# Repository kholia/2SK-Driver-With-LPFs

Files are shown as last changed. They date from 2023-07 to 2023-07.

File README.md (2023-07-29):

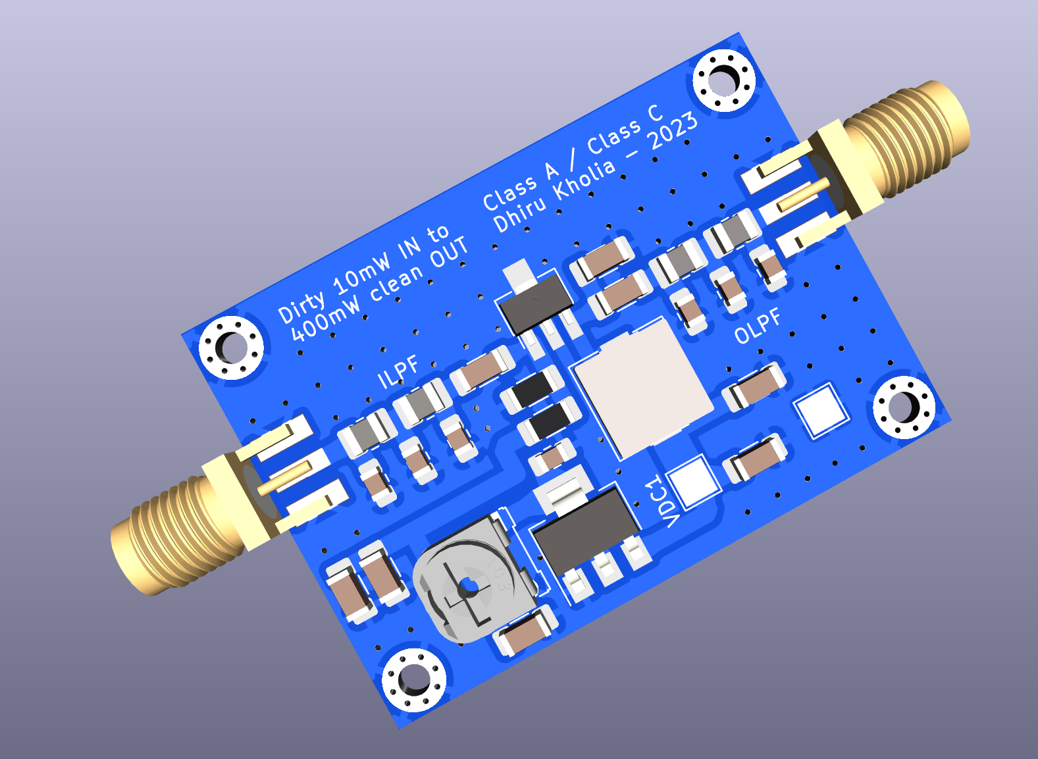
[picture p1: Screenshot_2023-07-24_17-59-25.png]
PCB render


This PCB was validated in July, 2023.

It outputs around 210mW into a dummy load @ 28 MHz even without any matching at
the output side. This is more than enough to drive RD16HHF1-501 easily.

Input is ~10mW straight from a Si5351 clone module.

We should probably add some simple LC matching at the output side one day.

Measurements on tinySA after 50 dB attentuation:

```
-24.4 dBm - Fc

-71.9 dBm -> second harmonic

dBc = ~47
```

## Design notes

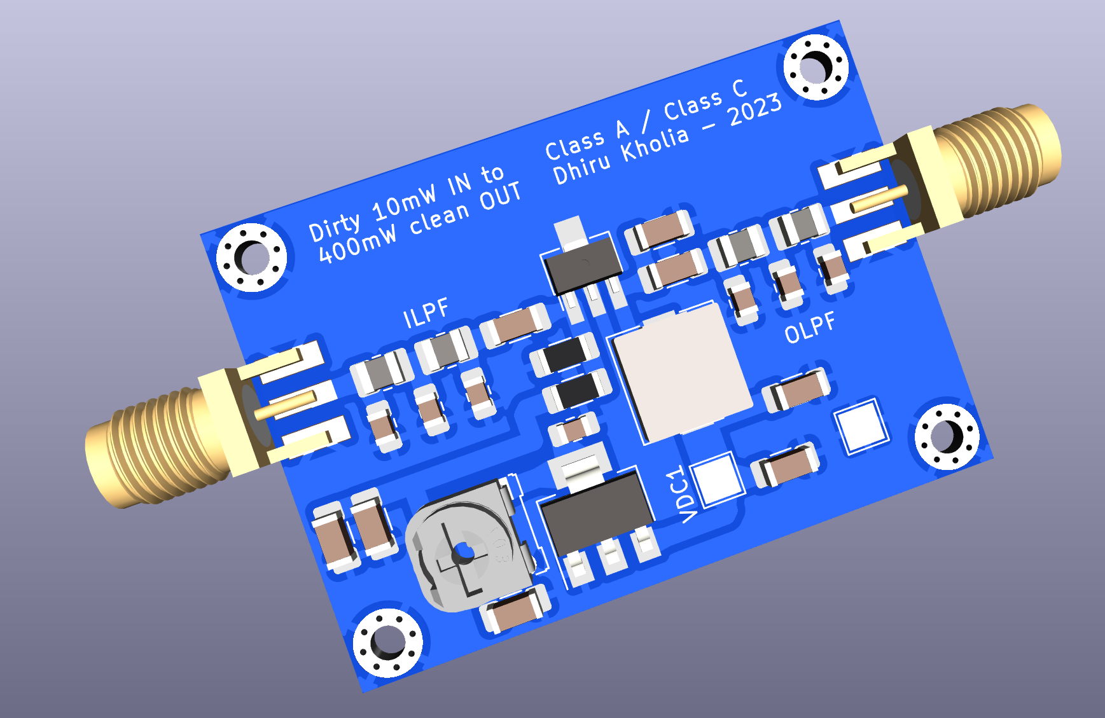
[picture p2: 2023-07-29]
Screenshot_2023-07-24_17-48-51.png

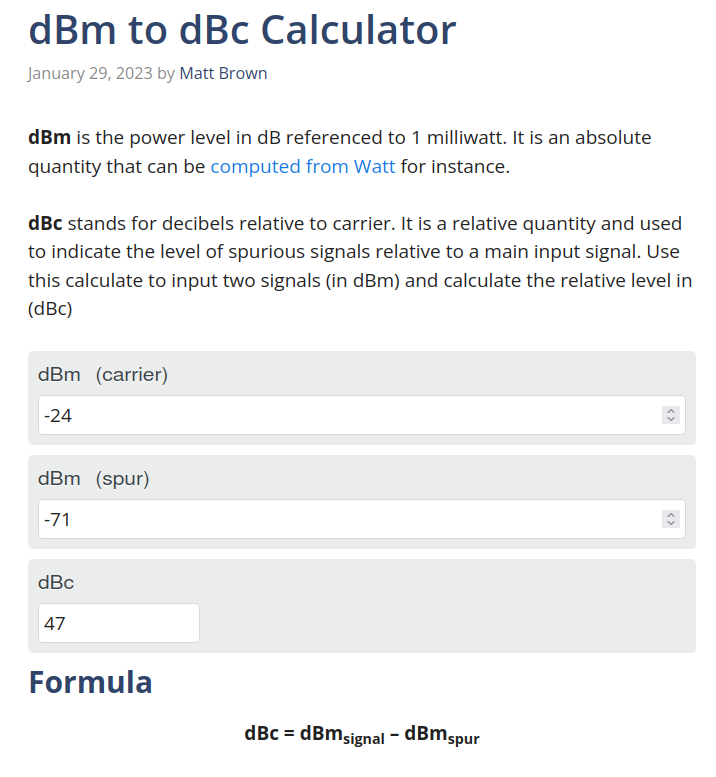
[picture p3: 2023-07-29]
Screenshot_2023-07-20_23-33-54.png

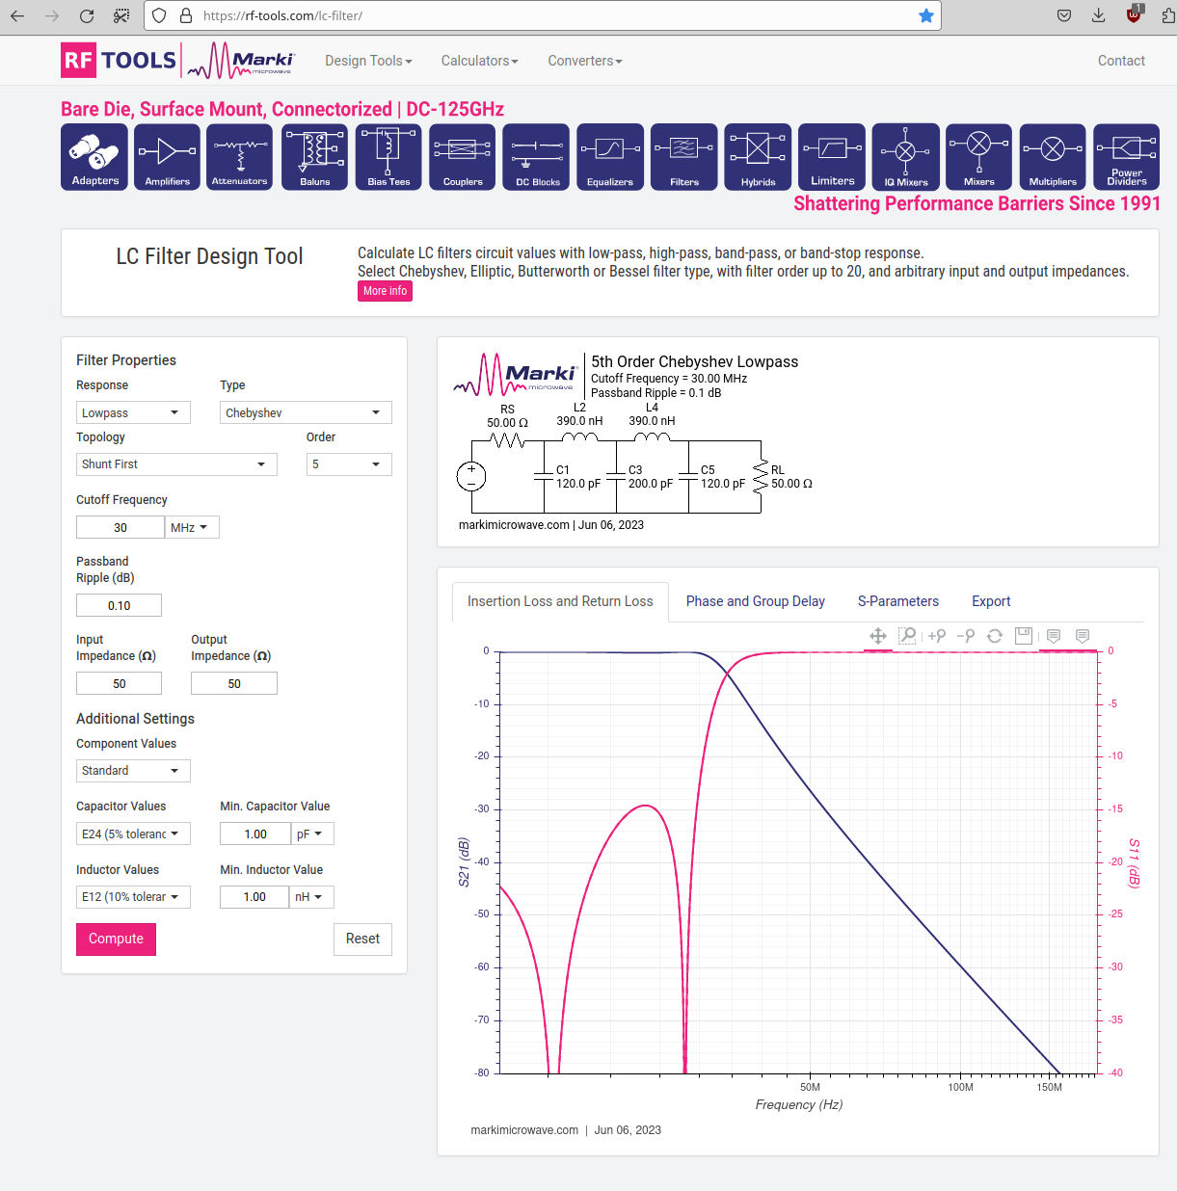
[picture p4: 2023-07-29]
simulations/Screenshot_2023-06-06_22-12-02.png

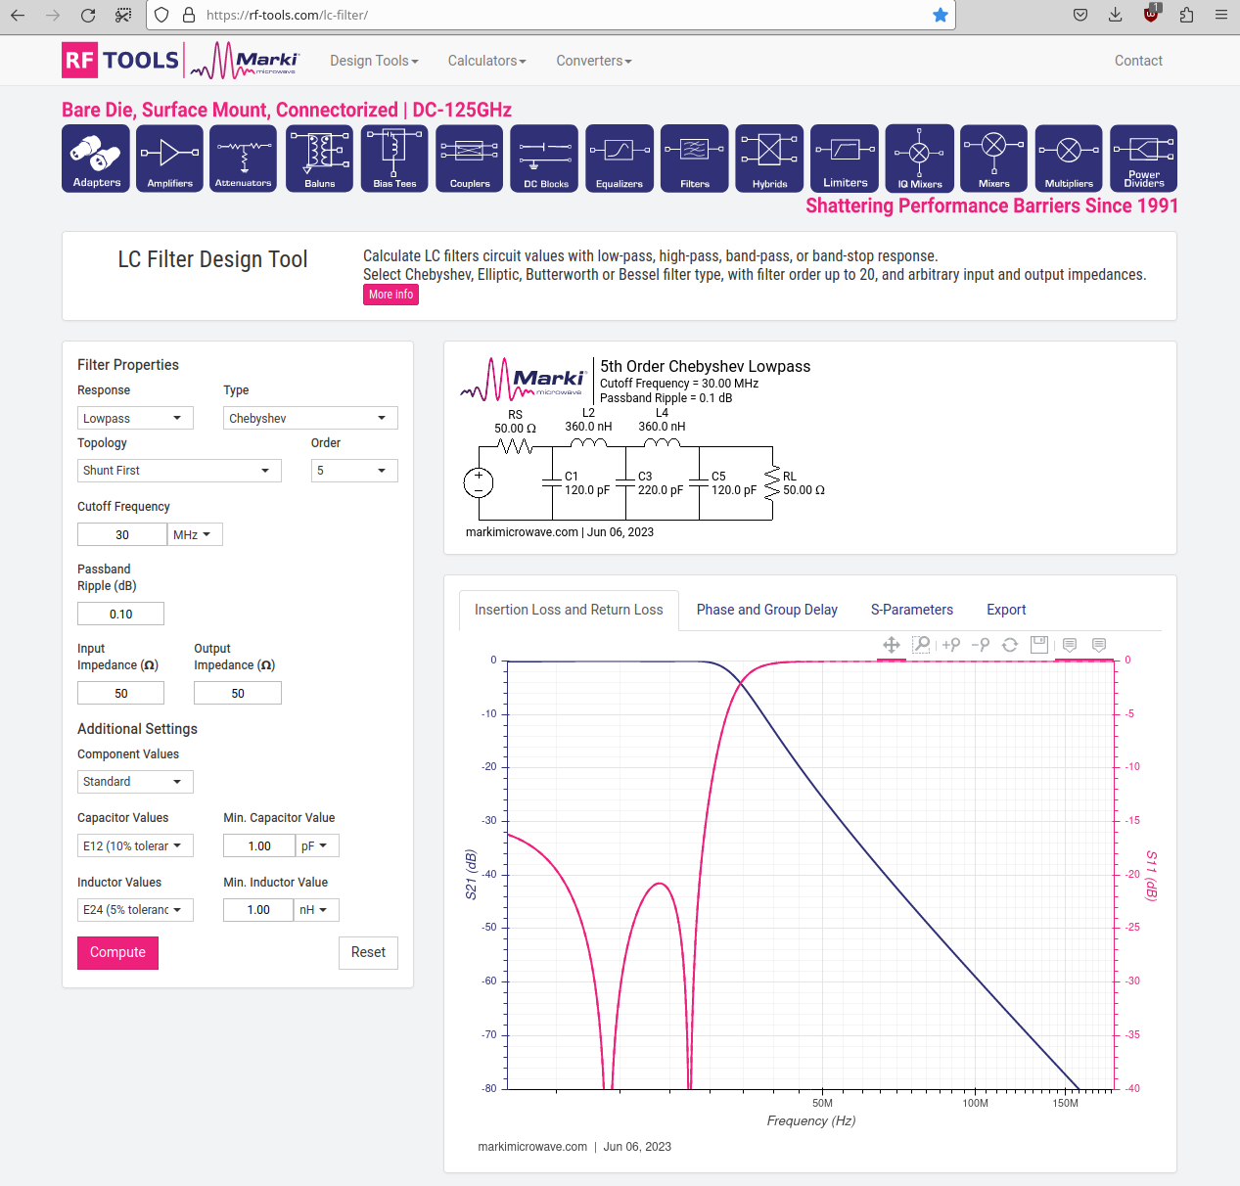
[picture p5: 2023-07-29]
simulations/Screenshot_2023-06-06_21-58-15.png

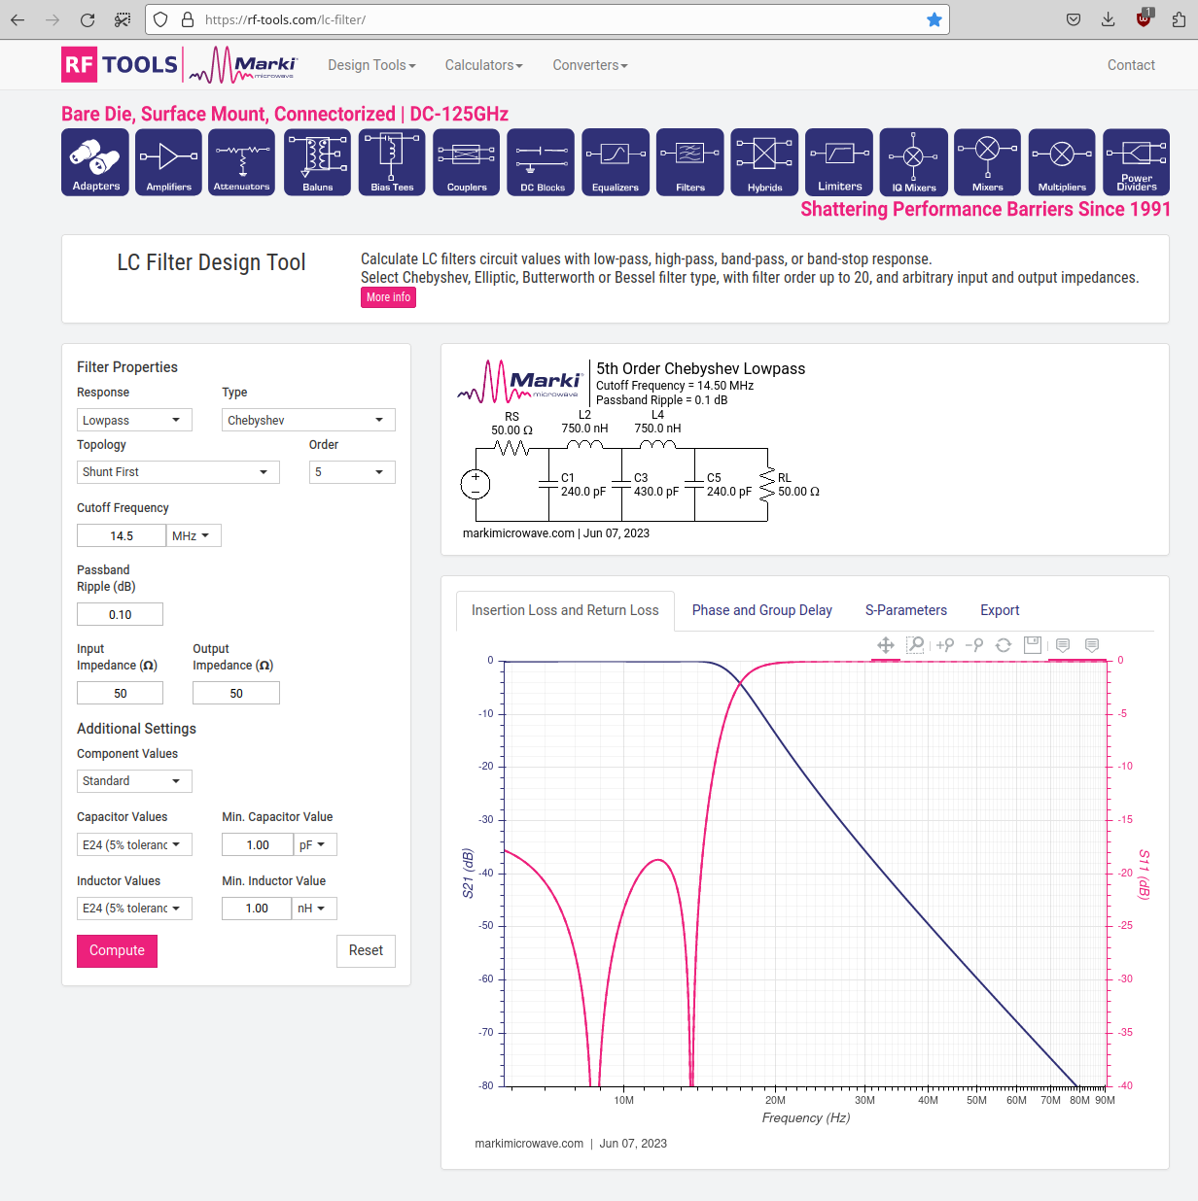
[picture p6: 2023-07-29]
simulations/Screenshot_2023-06-07_12-02-53.png

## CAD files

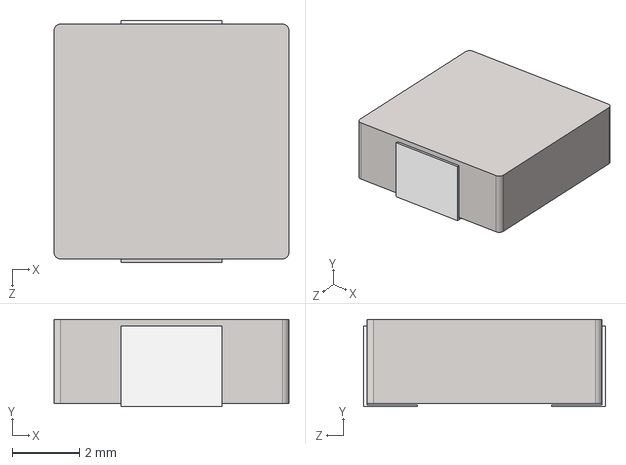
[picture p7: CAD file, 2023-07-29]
models/Inductor_7x7x2.5.STEP
7.00 x 2.60 x 7.20 mm

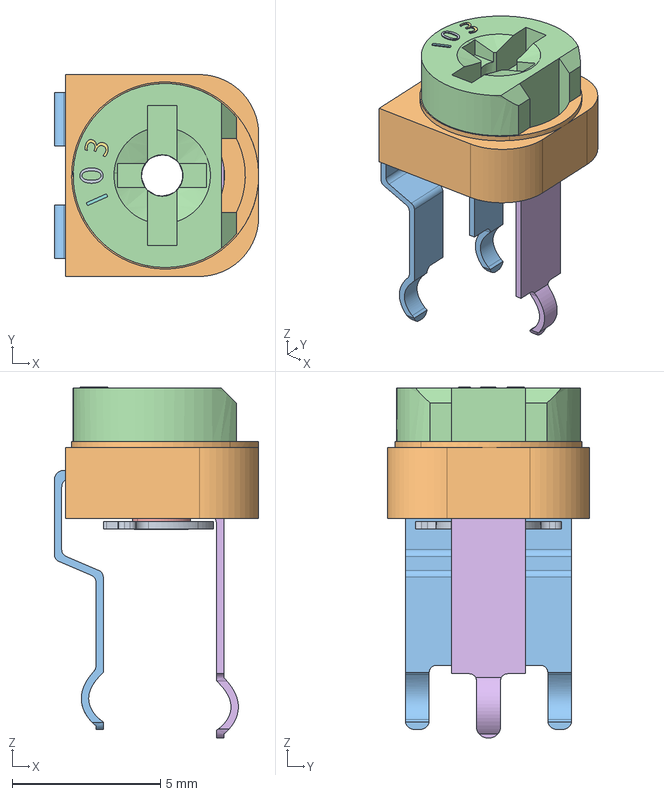
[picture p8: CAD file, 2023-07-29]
models/Poti_10kohm.stp
6.88 x 6.80 x 11.8 mm

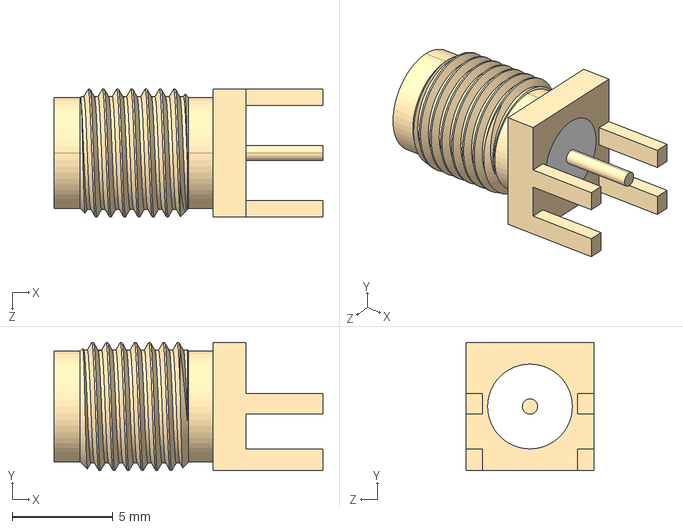
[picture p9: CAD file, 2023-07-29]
models/CON-SMA-EDGE-S--3DModel-STEP-56544.STEP
13.3 x 6.35 x 6.35 mm

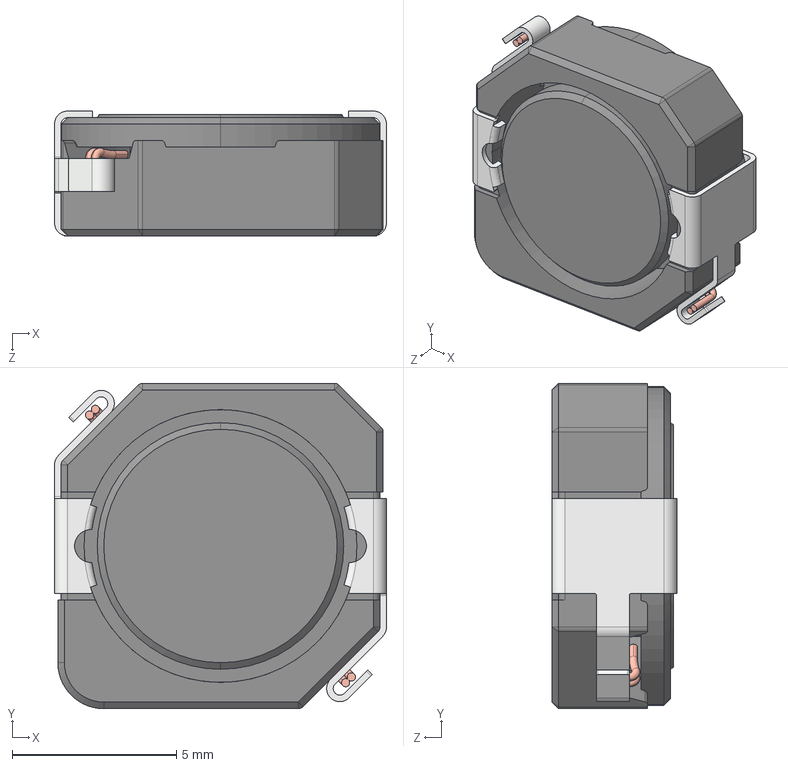
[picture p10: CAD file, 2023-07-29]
models/CDRH104R.STEP
10.1 x 9.90 x 3.80 mm

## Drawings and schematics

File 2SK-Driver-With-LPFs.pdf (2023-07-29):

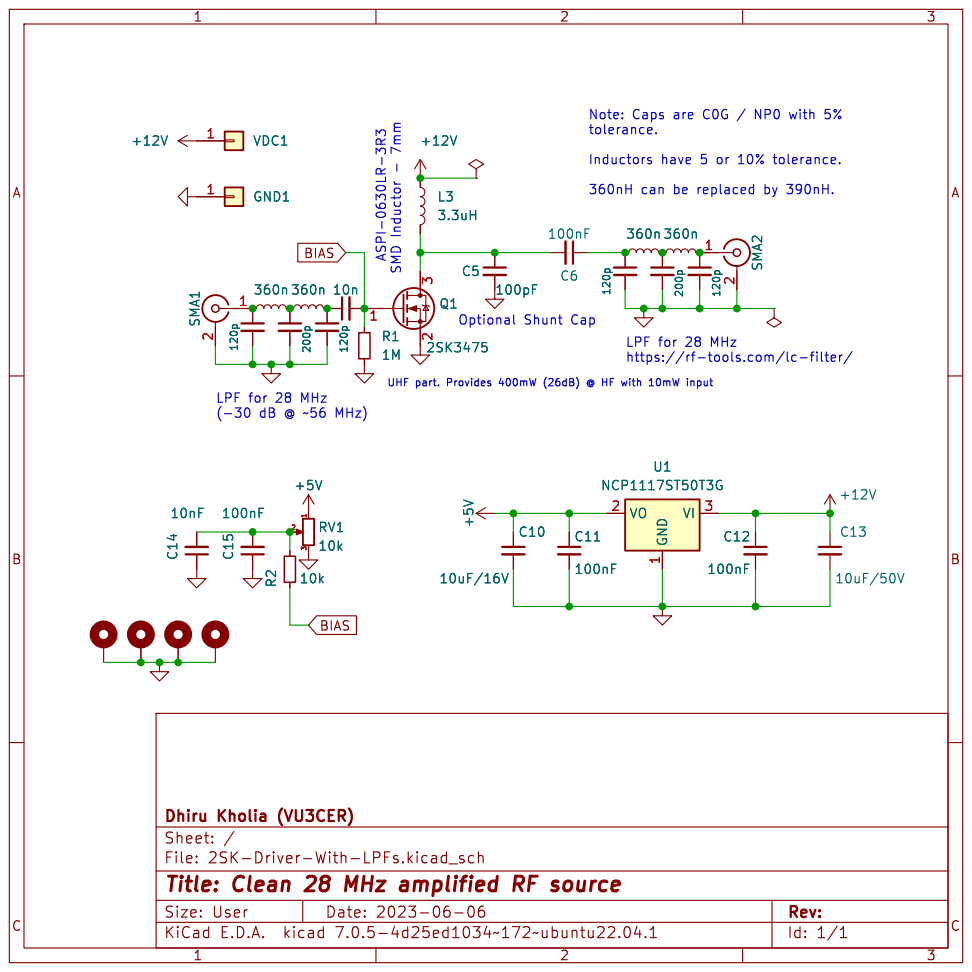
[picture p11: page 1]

LPF for 28 MHz https://rf-tools.com/lc-filter/ Note: Caps are C0G / NP0 with 5%
tolerance.

UHF part. Provides 400mW (26dB) @ HF with 10mW input LPF for 28 MHz

Id: 1/1 Title: Clean 28 MHz amplified RF source

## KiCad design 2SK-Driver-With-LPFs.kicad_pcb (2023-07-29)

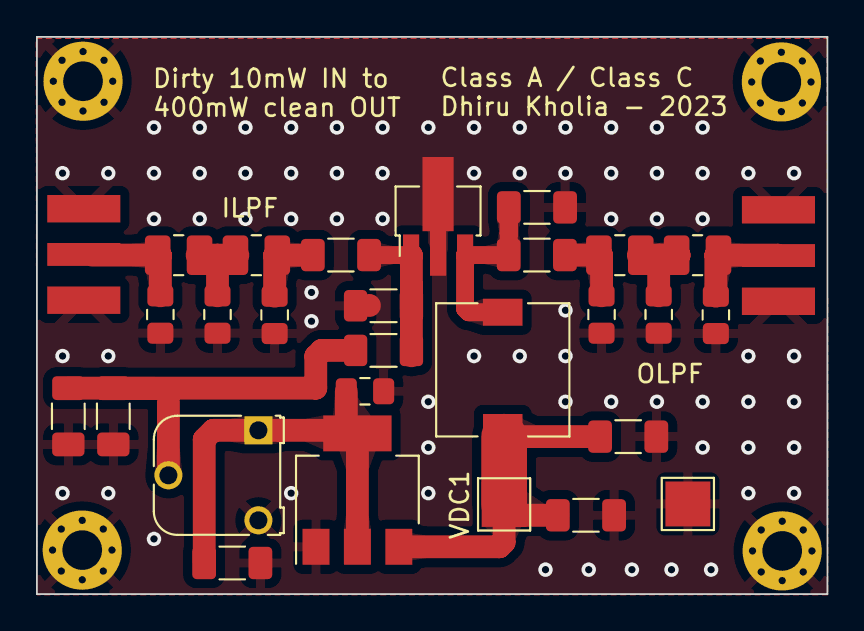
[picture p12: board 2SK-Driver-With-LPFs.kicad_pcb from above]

Board: 2 copper layers, 43.9 x 31.0 mm, 33 parts (0 on the bottom side), 12 nets.

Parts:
C1, C3, C7, C9: 120p; C_0805_2012Metric_Pad1.18x1.45mm_HandSolder
C2, C8: 200p; C_0805_2012Metric_Pad1.18x1.45mm_HandSolder
C4: 10n; C_1206_3216Metric_Pad1.33x1.80mm_HandSolder
C5: 100pF; C_1206_3216Metric_Pad1.33x1.80mm_HandSolder
C6, C12, C15: 100nF; C_1206_3216Metric_Pad1.33x1.80mm_HandSolder
C10: 10uF/16V; C_1206_3216Metric_Pad1.33x1.80mm_HandSolder
C11: 100nF; C_0805_2012Metric_Pad1.18x1.45mm_HandSolder
C13: 10uF/50V; C_1206_3216Metric_Pad1.33x1.80mm_HandSolder
C14: 10nF; C_1206_3216Metric_Pad1.33x1.80mm_HandSolder
GND1: Conn_01x01; TestPoint_Pad_2.5x2.5mm
H1, H2, H3, H4: MountingHole_Pad; MountingHole_2.2mm_M2_Pad_Via
L1, L2, L4, L5: 360n; L_1008_2520Metric_Pad1.43x2.20mm_HandSolder
L3: 3.3uH; L_7.3x7.3_H3.5
Q1: 2SK3475; SOT-89-3_Handsoldering
R1: 1M; R_1206_3216Metric_Pad1.30x1.75mm_HandSolder
R2: 10k; R_1206_3216Metric_Pad1.30x1.75mm_HandSolder
RV1: 10k; Potentiometer_Runtron_RM-065_Vertical
SMA1, SMA2: SMA; SMA_EDGELAUNCH_Modded
U1: NCP1117ST50T3G; SOT-223-3_TabPin2
VDC1: Conn_01x01; TestPoint_Pad_2.5x2.5mm

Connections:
+5V: C10.1, C11.1, RV1.1, U1.2 (VO)
+12V: C12.1, C13.1, L3.1, U1.3 (VI), VDC1.1
BIAS: C4.2, Q1.1 (G), R1.1, R2.2
GND: C1.2, C2.2, C3.2, C5.2, C7.2, C8.2, C9.2, C10.2, C11.2, C12.2, C13.2, C14.1, C15.1, GND1.1, H1.1, H2.1, H3.1, H4.1, Q1.2 (S), R1.2, RV1.3, SMA1.2 (Ext), SMA2.2 (Ext), U1.1 (GND)
unnamed: C2.1, L1.2, L2.1
unnamed: C3.1, C4.1, L2.2
unnamed: C6.1, C7.1, L4.1
unnamed: C8.1, L4.2, L5.1
unnamed: C14.2, C15.2, R2.1, RV1.2
unnamed: C5.1, C6.2, L3.2, Q1.3 (D)
unnamed: C1.1, L1.1, SMA1.1 (In)
unnamed: C9.1, L5.2, SMA2.1 (In)
